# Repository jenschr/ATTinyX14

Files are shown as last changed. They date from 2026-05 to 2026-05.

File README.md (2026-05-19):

# ATTinyX14 development board
Tiny breadboard compatible development board that can contain either an ATTiny414, ATTiny814 or ATTiny1614 - depending on your need for Flash memory. This repo contains the complete Kicad design files under an MIT license as well as documentation, pinout & images of the verified design. I'm a consultant based in Oslo/Norway, so [get in touch](https://maketronics.no/about/) if you need custom hardware based on ATTiny or [other MCUs](https://flashgamer.com/blog/comments/microcontroller-reference-boards).

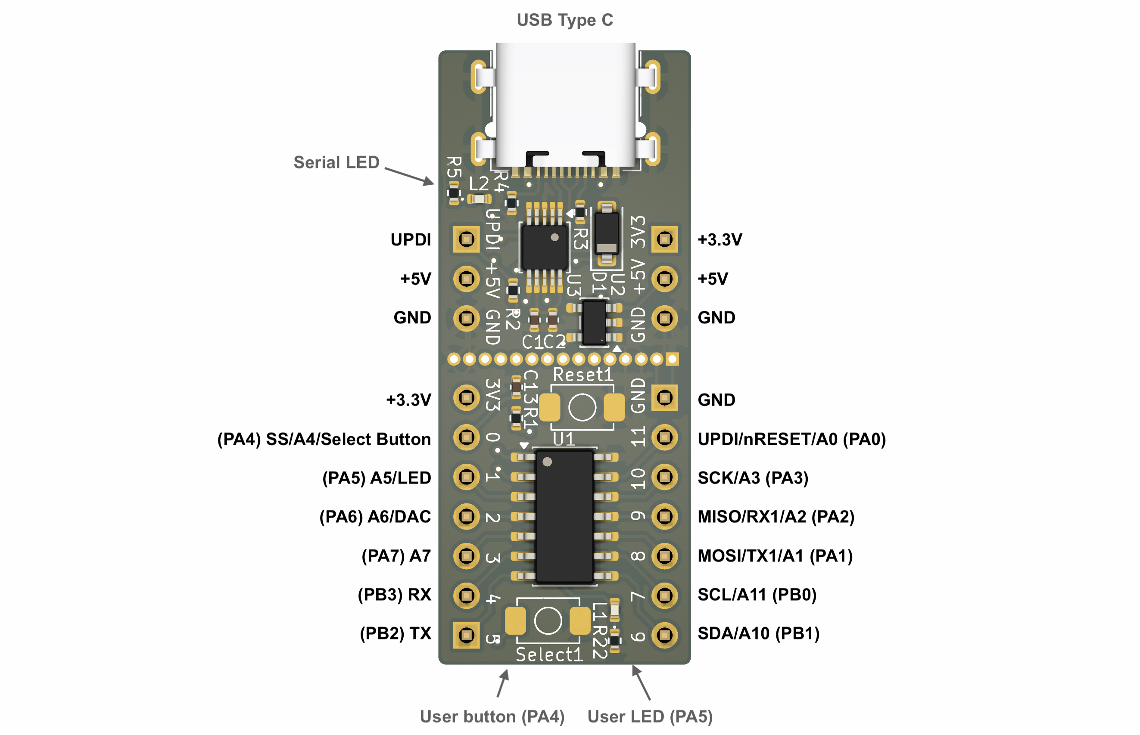
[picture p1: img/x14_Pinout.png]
ATTinyX14 Pinout


## Features
This nifty little microcontroller paired with the CH340 serial chip, makes for a very compact development board. Due to it's tiny size, you have 3 rows on each side of the breadboard to connect jumper wires to. When used with Spence Konde's brilliant [megaTinyCore](https://github.com/SpenceKonde/megaTinyCore), this is very smooth to use for prototyping.

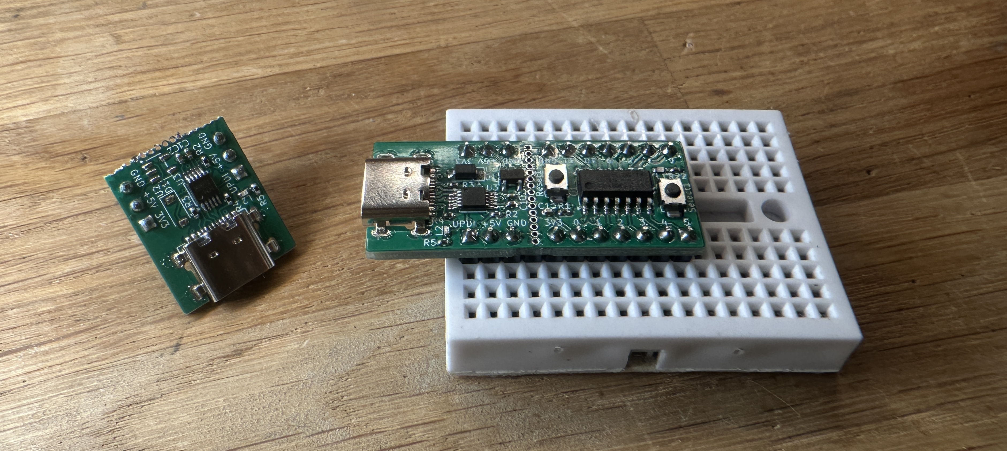
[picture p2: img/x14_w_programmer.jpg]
ATTinyX14 compactness


The board has a builtin LED on (PA5) and a button (PA4) for testing. The Serial chip has a LED on the TX line, so you can visually inspect when programming is done and finished. My primary reason for looking at this chip series was the 8-bit DAC output on PA6. Very few MCU's in this price range has a builtin DAC, so it is very handy for many types projects such as controlling devices based on voltage. One such example is controlling 0-10V motors/fans by just adding a small OpAmp circuit.

Some things to note:

### 2-in-one
The UPDI programmer can be cut away, so you can use the MCU and programmer separately. In that case, the MCU must be powered separately, since the 3.3V regulator sits on the UPDI Programmer.

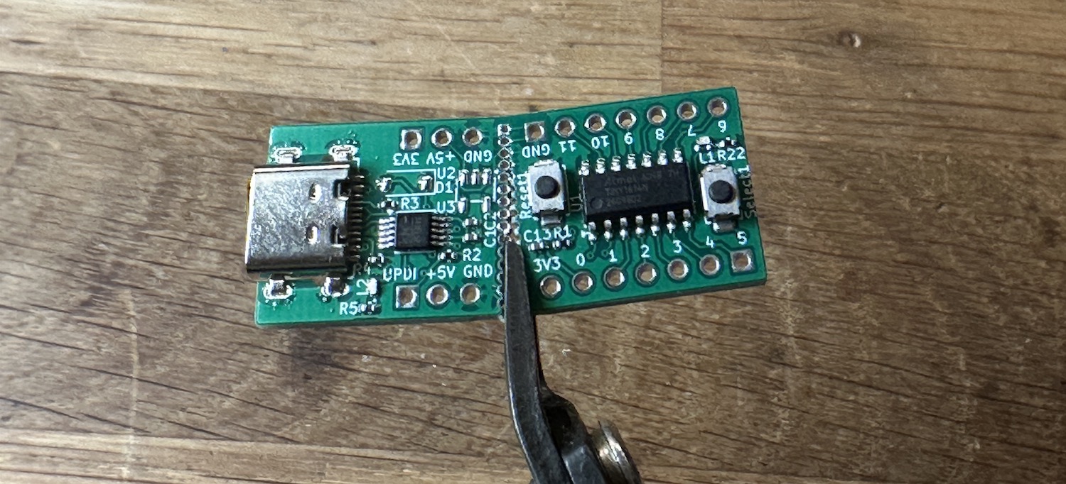
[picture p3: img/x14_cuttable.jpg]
ATTinyX14 cuttable


### Drawbacks
One drawback is that the setup does not allow for direct Serial debugging. You have to connect a separate Serial Converter/Adapter ([like this one](https://www.taydaelectronics.com/cp2102-serial-converter-usb-2-0-to-ttl-uart-ftdi.html) or anything similar) to use Arduino's Serial.

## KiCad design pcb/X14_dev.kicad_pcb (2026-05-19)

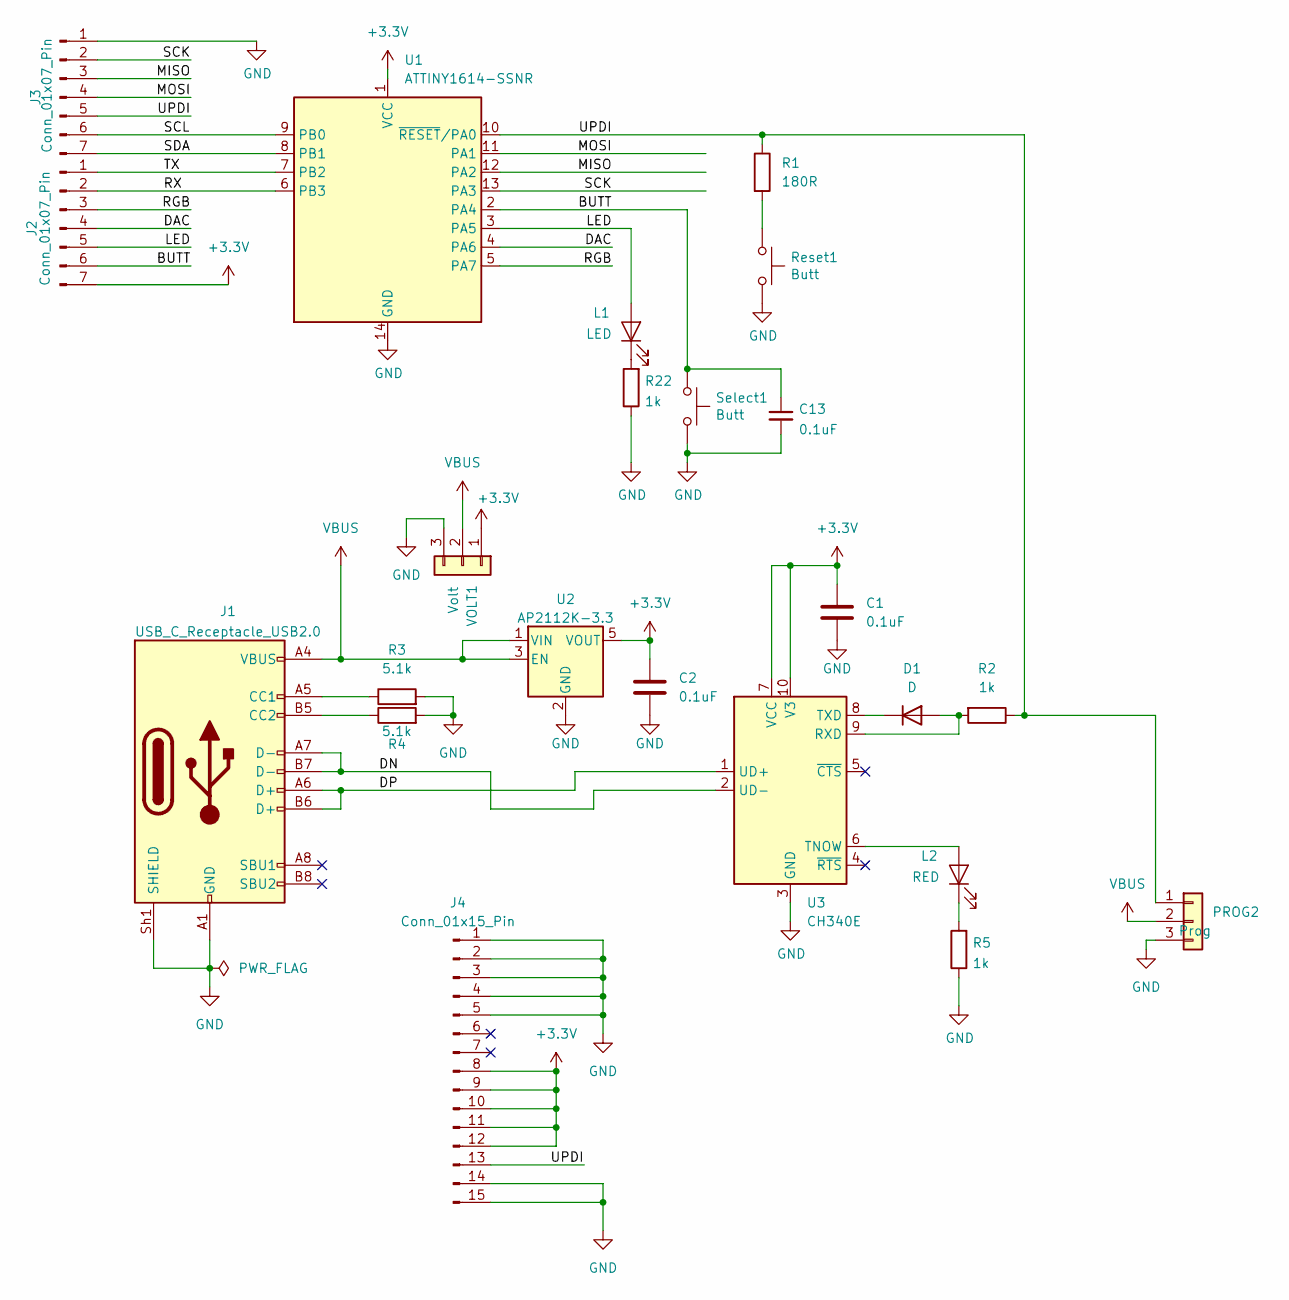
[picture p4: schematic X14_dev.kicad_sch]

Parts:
C1, C2: 0.1uF; C_0402_1005Metric; MPN CL05B104KA5NNNC
C13: 0.1uF; C_0402_1005Metric
D1: D; D_SOD-123
J1: USB_C_Receptacle_USB2.0; TYPE-C-31-M-14; MPN TYPE-C-31-M-14; LCSC Part # C223907
J2, J3: Conn_01x07_Pin; PinHeader_1x07_P2.54mm_Vertical
J4: Conn_01x15_Pin; PinHeader_1x16_P1.00mm_Vertical
L1: LED; LED_0402_1005Metric
L2: RED; LED_0402_1005Metric
PROG2: Prog; PinHeader_1x03_P2.54mm_Vertical
R1: 180R; R_0402_1005Metric
R2, R5, R22: 1k; R_0402_1005Metric
R3, R4: 5.1k; R_0402_1005Metric
Reset1: Butt; TS-1088-AR02016; MPN TS-1088-AR02016; LCSC C720477
Select1: Butt; TS-1088-AR02016; MPN TS-1088-AR02016; LCSC C720477
U1: ATTINY1614-SSNR; SOIC-14_3.9x8.7mm_P1.27mm; MPN ATTINY1614-SSNR; LCSC C481364
U2: AP2112K-3.3; SOT-23-5; MPN AP2112K-3.3TRG1
U3: CH340E; MSOP-10_3x3mm_P0.5mm
VOLT1: Volt; PinHeader_1x03_P2.54mm_Vertical

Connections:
+3.3V: C1.2, C2.2, J2.7, J4.8, J4.9, J4.10, J4.11, J4.12, U1.1 (VCC), U2.5 (VOUT), U3.7 (VCC), U3.10 (V3), VOLT1.1
/BUTT: C13.1, J2.6, Select1.1, U1.2 (PA4)
/DAC: J2.4, U1.4 (PA6)
/DN: J1.A7 (D-), J1.B7 (D-), U3.2 (UD-)
/DP: J1.A6 (D+), J1.B6 (D+), U3.1 (UD+)
/LED: J2.5, L1.2 (A), U1.3 (PA5)
/MISO: J3.3, U1.12 (PA2)
/MOSI: J3.4, U1.11 (PA1)
/RGB: J2.3, U1.5 (PA7)
/RX: J2.2, U1.6 (PB3)
/SCK: J3.2, U1.13 (PA3)
/SCL: J3.6, U1.9 (PB0)
/SDA: J3.7, U1.8 (PB1)
/TX: J2.1, U1.7 (PB2)
/UPDI: J3.5, J4.13, PROG2.1, R1.1, R2.1, U1.10 (~RESET/PA0)
GND: C1.1, C2.1, C13.2, J1.A1 (GND), J1.A12 (GND), J1.B1 (GND), J1.B12 (GND), J1.Sh1 (SHIELD), J3.1, J4.1, J4.2, J4.3, J4.4, J4.5, J4.14, J4.15, PROG2.3, R3.2, R4.2, R5.1, R22.1, Reset1.2, Select1.2, U1.14 (GND), U2.2 (GND), U3.3 (GND), VOLT1.3
unnamed: D1.2 (A), R2.2, U3.9 (RXD)
unnamed: D1.1 (K), U3.8 (TXD)
unnamed: J1.A5 (CC1), R3.1
unnamed: J1.B5 (CC2), R4.1
unnamed: L1.1 (K), R22.2
unnamed: L2.2 (A), U3.6 (TNOW)
unnamed: L2.1 (K), R5.2
unnamed: R1.2, Reset1.1
VBUS: J1.A4 (VBUS), J1.A9 (VBUS), J1.B4 (VBUS), J1.B9 (VBUS), PROG2.2, U2.1 (VIN), U2.3 (EN), VOLT1.2

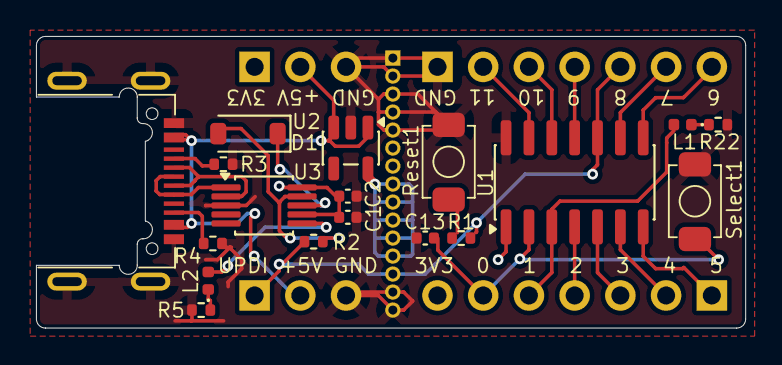
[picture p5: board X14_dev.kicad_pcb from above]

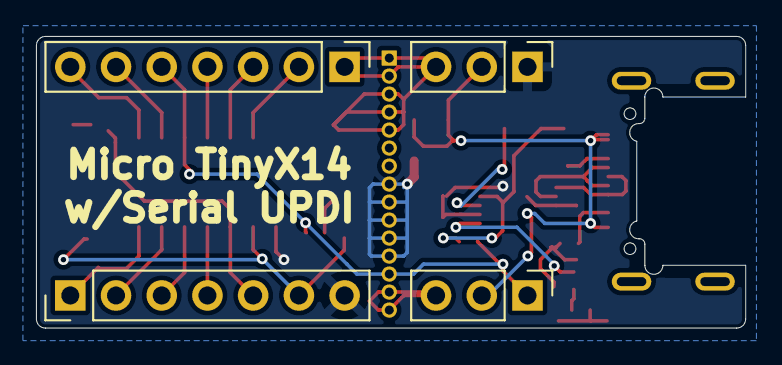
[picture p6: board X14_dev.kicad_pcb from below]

Board: 2 copper layers, 39.4 x 16.2 mm, 23 parts (4 on the bottom side), 25 nets.

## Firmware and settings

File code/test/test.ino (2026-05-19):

/*
 * Basic test-sketch for button and LED on x14 devboard
 */


#define PA4 0  // SS/A4/Button
#define PA5 1  // A5/LED
#define PA6 2  // A6/DAC
#define PA7 3  // A7
#define PB3 4  // RX
#define PB2 5  // TX
#define PB1 6  // SDA/A10
#define PB0 7  // SCL/A11
#define PA1 8  // MOSI/TX1/A1
#define PA2 9  // MISO/RX1/A2
#define PA3 10 // SCK/A3
#define PA0 11 // UPDI programming

int count = 0;
bool wasButtonPressed = false;

void setup() {
  Serial.begin(9600);
  delay(4000);
  Serial.println("test");
  pinMode(PA5, OUTPUT);       // LED
  pinMode(PA4, INPUT_PULLUP); // Button
}

void loop() {
  // If button is pressed, keep LED turned on
  bool isButtonPressed = !digitalRead(PA4);
  if( isButtonPressed != wasButtonPressed ){
    Serial.println( isButtonPressed );
    digitalWrite( PA5, isButtonPressed );
    delay(100);// simple debounce
  }
  wasButtonPressed = isButtonPressed;

  // Toggle LED every 10000 loops
  if( !isButtonPressed && count % 10000 == 0 ){
    digitalWrite( PA5, !digitalRead(PA5) );
  } else if( isButtonPressed ){
    analogWrite( PA5, (count % 255) );
    delay(3);
  }
  count++;
}
